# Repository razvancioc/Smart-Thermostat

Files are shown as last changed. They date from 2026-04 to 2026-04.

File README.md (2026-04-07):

# ESP32-Smart-Thermostat-Blynk-APP





**Full Doxygen Documentation:** [Click here to see it](https://razvancioc.github.io/Smart-Thermostat/)

<p align="center">
  
  <br>
  
  <br>
  
  <br>
  
  <br>
  
</p>

## Bill of Materials (BOM)

| Item / Component | Qty | Specifications / Model | Role in Project |
| :--- | :---: | :--- | :--- |
| **Microcontroller** | 1 | ESP32 Development Board | Main brain, Wi-Fi connectivity, and UI rendering. |
| **Display** | 1 | 1.69" IPS LCD Module | ST7789 driver, 240x280 resolution, SPI interface. |
| **Sensor** | 1 | DHT11 Module | Temperature and humidity reading (3-pin variant). |
| **Relay** | 1 | CW-020 5V Module | Low-level trigger; actuates the boiler's dry contact. |
| **Wiring** | Set | Jumper Wires (Dupont) | For connections between modules. |
| **Power Supply** | 1 | 5V Power Source (USB) | Powers the ESP32, which in turn provides 3.3V to the peripherals. |

## Hardware Schematic

<p align="center">
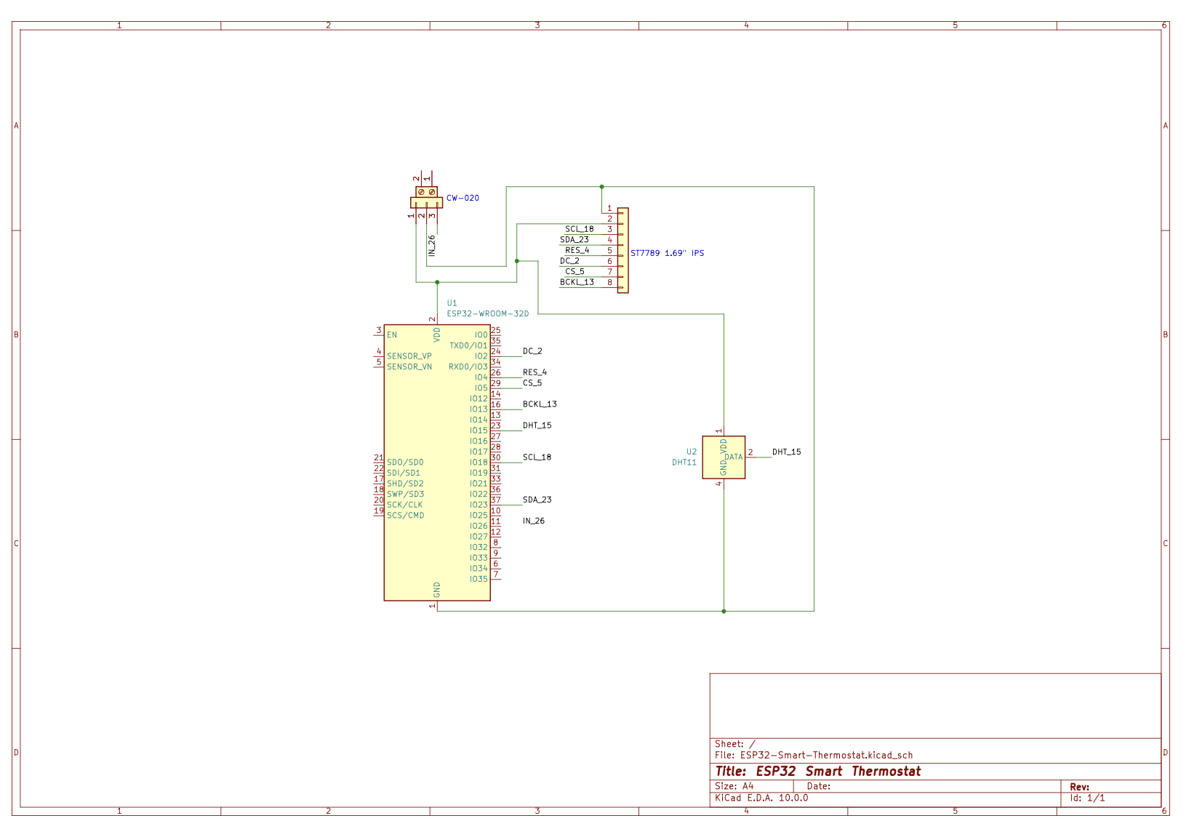
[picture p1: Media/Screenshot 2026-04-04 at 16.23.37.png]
  
</p>

## The Build Process & Engineering Journey

Building this thermostat wasn't just about putting parts together; it involved solving real hardware and software constraints. Here is how the project evolved:

### Phase 1: Breadboard Prototyping & Sensor Logic
The project started on a messy breadboard. The primary goal was to establish reliable communication between the ESP32, the DHT11 sensor, and the Blynk IoT cloud. 
* **Challenge:** The DHT11 sensor reading blocked the main loop. 
* **Solution:** Implemented `BlynkTimer` to read the sensor asynchronously every 2 seconds without halting the microcontroller.

### Phase 2: Designing the Neumorphic UI & Beating RAM Limits
I wanted a premium, "Frosted Glass" UI similar to modern smart home hubs (like Ecobee). 
* **Challenge:** Drawing complex graphics and clearing the screen (`fillScreen`) on an IPS display caused severe flickering. Attempting to use a full RAM Sprite (off-screen buffer) resulted in static/memory corruption because the ESP32 didn't have the contiguous ~134KB of free RAM required while running WiFi cryptography in the background.
* **Solution:** I engineered a **State-Tracking System**. The display now only redraws specific elements *if and only if* the temperature, humidity, or setpoint changes. Furthermore, to achieve the "transparent" text effect without RAM-heavy sprites, I dynamically matched the text background color to the underlying frosted glass circle color.

### Phase 3: Hardware Actuation & Hysteresis
Connecting the 5V CW-020 relay to safely control a boiler's dry contact.
* **Challenge:** Preventing "short-cycling" (the boiler turning on/off rapidly when the room temperature hovers exactly around the target).
* **Solution:** Programmed a `0.5°C` hysteresis logic. If the target is 22°C, heating starts at 21.5°C and stops at 22.5°C, protecting the physical hardware from premature wear.

### Phase 4: PCB Design & Professional Workflows
Transitioned from the breadboard to a formal schematic using **KiCad** to document the exact pinouts, logic-level power distribution, and safe relay wiring for future PCB fabrication. The codebase was also migrated from Arduino IDE to **Visual Studio Code (C++)**, complete with automated **Doxygen** documentation for clean, maintainable architecture.

---

## ⚠️ Critical Display Configuration (TFT_eSPI)

**Important:** If you simply compile the `main.cpp` file, the display will remain blank (white screen). The `TFT_eSPI` library requires hardware-specific configurations to know which display driver and pins you are using.

You need to inject the display settings directly into your `platformio.ini` file using build flags. Add the following to your `platformio.ini`:

```ini
build_flags =
  -D USER_SETUP_LOADED=1
  -D ST7789_DRIVER=1
  -D TFT_WIDTH=240
  -D TFT_HEIGHT=280
  -D TFT_MOSI=23
  -D TFT_SCLK=18
  -D TFT_CS=5
  -D TFT_DC=2
  -D TFT_RST=4
  -D LOAD_GLCD=1
  -D LOAD_FONT2=1
  -D LOAD_FONT4=1
  -D LOAD_FONT6=1
  -D SPI_FREQUENCY=27000000

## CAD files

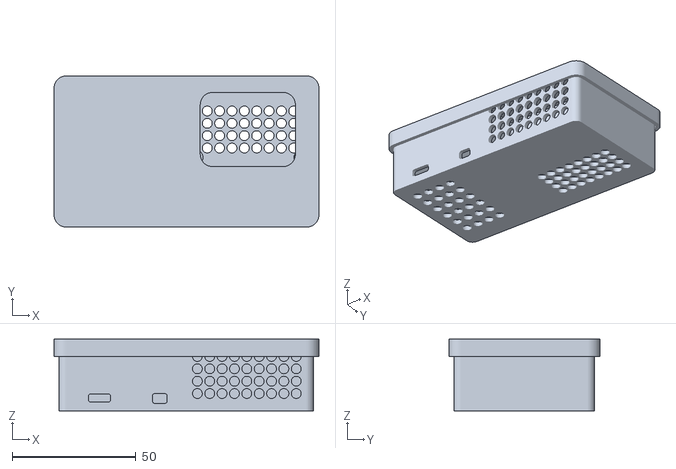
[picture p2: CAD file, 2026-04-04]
ESP32 Smart Thermostat Case.stl
107.2 x 61.2 x 29.0

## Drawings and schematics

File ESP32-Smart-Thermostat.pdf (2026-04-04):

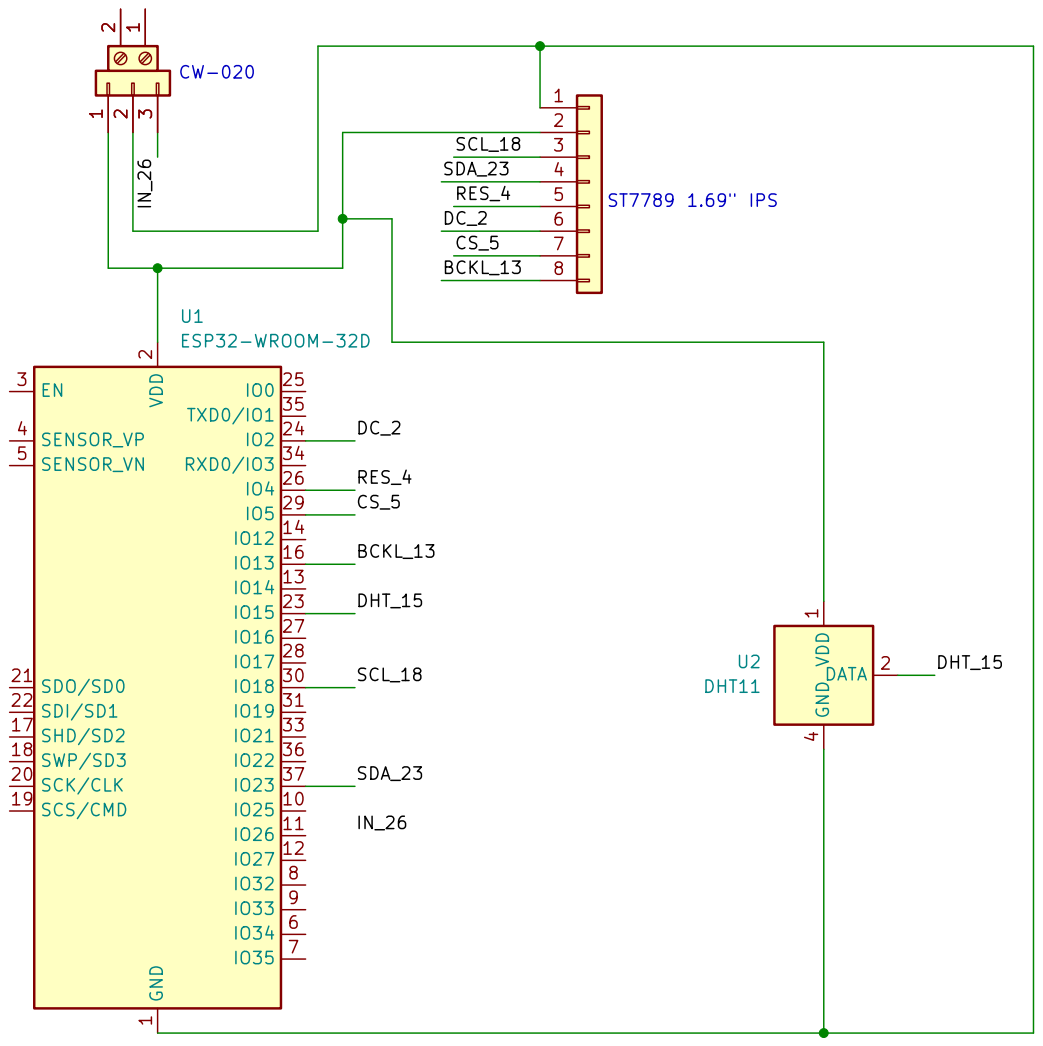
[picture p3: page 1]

Size: A4 | Rev:
KiCad E.D.A. 10.0.0 | Id: 1/1

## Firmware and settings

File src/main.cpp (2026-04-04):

/**
 * @file main.cpp
 * @brief ESP32 Smart Thermostat with TFT Display and Blynk Integration.
 * * This firmware reads environmental data from a DHT sensor, controls a heating 
 * relay based on a target setpoint with hysteresis, and displays a dynamic, 
 * anti-flickering user interface on an SPI TFT screen.
 */

// BLYNK CONFIGURATION 
#define BLYNK_TEMPLATE_ID "TMPLxxxxxxxxx"
#define BLYNK_TEMPLATE_NAME "My Thermostat"
#define BLYNK_AUTH_TOKEN "AbCdEfGhIjKlMnOpQrStUvWxYz123456"

// WIFI CONFIGURATION 
char ssid[] = "YOUR_WIFI_SSID";
char pass[] = "YOUR_WIFI_PASSWORD";

#include <WiFi.h>
#include <WiFiClient.h>
#include <BlynkSimpleEsp32.h>
#include <TFT_eSPI.h> 
#include <DHT.h>

// PINS AND HARDWARE 
#define RELAY_PIN 26
#define SENSOR_PIN 15
#define SENSOR_TYPE DHT11 
#define BACKLIGHT_PIN 13 

/** * @brief Relay Logic configuration.
 * CW-020 Relays are usually Low-Level Trigger, meaning pulling the pin to GND turns the relay ON.
 */
#define RELAY_ON LOW   
#define RELAY_OFF HIGH

DHT dht(SENSOR_PIN, SENSOR_TYPE);
TFT_eSPI tft = TFT_eSPI(); 
BlynkTimer timer;

// CURRENT VARIABLES 
float currentTemp = 0;
float humidity = 0;
float targetTemp = 22.0; 
float hysteresis = 0.5;  /**< Temperature gap to prevent rapid relay switching */
bool isHeating = false;  

// STATE TRACKING VARIABLES (For Anti-Flicker Logic)
float lastTemp = -999;
float lastHumidity = -999;
float lastTarget = -999;
bool lastHeatingState = !isHeating;
bool forceRedraw = true; /**< Forces a full screen wipe and redraw on the first boot cycle */

// COLOR PALETTE
#define COLOR_PANEL_BG TFT_BLACK 
#define COLOR_PANEL_FROST 0x2104 
#define COLOR_HEATING 0xFB00 
#define COLOR_HUMIDITY 0x3DFF 
#define COLOR_GREY_TEXT 0x8410 
#define COLOR_TEXT_WHITE TFT_WHITE

/**
 * @brief XBM Image Data for the Humidity Drop.
 * The PROGMEM keyword forces the microcontroller to store this array in Flash memory
 * instead of RAM, leaving more RAM available for dynamic variables.
 */
const unsigned char icon_drop[] PROGMEM = {
  0x00, 0x00, 0x00, 0x01, 0x80, 0x03, 0xc0, 0x07, 0xe0, 0x0f, 0xf0, 0x1f,
  0xf8, 0x3f, 0xfc, 0x7f, 0xfe, 0x7f, 0xfe, 0x7f, 0xfe, 0x3f, 0xfc, 0x1f,
  0xf8, 0x0f, 0xf0, 0x03, 0xc0, 0x00, 0x00, 0x00
};

/**
 * @brief XBM Image Data for the Heating Flame.
 */
const unsigned char icon_flame[] PROGMEM = {
  0x00, 0x00, 0x80, 0x00, 0xc0, 0x00, 0x60, 0x01, 0x30, 0x03, 0x18, 0x03,
  0xcc, 0x07, 0xce, 0x0f, 0x86, 0x1f, 0x03, 0x3f, 0x03, 0x3f, 0x82, 0x3f,
  0xc4, 0x1f, 0xf8, 0x0f, 0xf0, 0x03, 0x00, 0x00
};

/**
 * @brief Blynk App Callback: Target Temperature Slider.
 * Triggered automatically when the user changes the slider on the Blynk App (Virtual Pin 2).
 */
BLYNK_WRITE(V2) {
  targetTemp = param.asFloat();
  checkThermostat();
}

/**
 * @brief Blynk App Callback: Emergency Stop Button.
 * Forces the relay to turn off if the button on Virtual Pin 4 is pressed (value goes to 0).
 */
BLYNK_WRITE(V4) {
  if (param.asInt() == 0) {
    digitalWrite(RELAY_PIN, RELAY_OFF);
    isHeating = false;
  }
}

/**
 * @brief Standard Arduino Setup Function.
 * Initializes hardware pins, display, sensors, and network connections.
 */
void setup() {
  Serial.begin(115200);

  pinMode(BACKLIGHT_PIN, OUTPUT);
  digitalWrite(BACKLIGHT_PIN, HIGH); 
  
  pinMode(RELAY_PIN, OUTPUT);
  digitalWrite(RELAY_PIN, RELAY_OFF); 

  tft.init();
  tft.setRotation(3); 
  
  tft.fillScreen(COLOR_PANEL_BG);
  tft.setTextDatum(MC_DATUM); 
  tft.setTextColor(TFT_WHITE, COLOR_PANEL_BG); 
  tft.drawString("Connecting to WiFi...", tft.width()/2, tft.height()/2);

  dht.begin();
  Blynk.begin(BLYNK_AUTH_TOKEN, ssid, pass);

  timer.setInterval(2000L, readSensorAndControl);
}

/**
 * @brief Standard Arduino Loop Function.
 * Kept clean. Only processes Blynk cloud tasks and hardware timers.
 */
void loop() {
  Blynk.run();
  timer.run();
}

/**
 * @brief Core Application Logic.
 * Reads the DHT sensor, applies calibration offsets, updates the cloud, 
 * checks the thermostat rules, and triggers a UI redraw if any data changed.
 */
void readSensorAndControl() {
  float t = dht.readTemperature();
  float h = dht.readHumidity();

  if (isnan(t) || isnan(h)) return;

  // Temperature calibration offset (compensating for heat generated by the ESP32 chip)
  currentTemp = t - 3.0; 
  humidity = h;

  Blynk.virtualWrite(V0, currentTemp);
  Blynk.virtualWrite(V1, humidity);

  checkThermostat();

  // ANTI-FLICKER REDRAW LOGIC
  // Only redraw the display if a value has actually changed.
  // This prevents the screen from continuously blanking out and flickering every 2 seconds.
  if (currentTemp != lastTemp || humidity != lastHumidity || targetTemp != lastTarget || isHeating != lastHeatingState || forceRedraw) {
    drawInterface();
    
    lastTemp = currentTemp;
    lastHumidity = humidity;
    lastTarget = targetTemp;
    lastHeatingState = isHeating;
    forceRedraw = false;
  }
}

/**
 * @brief Evaluates the current temperature against the target setpoint.
 * Uses hysteresis to define a "deadband" so the relay doesn't rapidly click on and off 
 * when the temperature hovers exactly at the target.
 */
void checkThermostat() {
  if (currentTemp <= (targetTemp - hysteresis)) {
    digitalWrite(RELAY_PIN, RELAY_ON);
    Blynk.virtualWrite(V3, 1); 
    isHeating = true;
  } 
  else if (currentTemp >= (targetTemp + hysteresis)) {
    digitalWrite(RELAY_PIN, RELAY_OFF);
    Blynk.virtualWrite(V3, 0); 
    isHeating = false;
  }
}

/**
 * @brief Renders the Graphical User Interface on the TFT display.
 * Draws the central circle, dynamic sidebar, icons, and text.
 */
void drawInterface() {
  int w = tft.width();
  int h = tft.height();
  int centerX = (w / 2) - 15; 
  int centerY = h / 2;
  
  tft.fillScreen(COLOR_PANEL_BG);

  tft.fillCircle(centerX, centerY, 65, COLOR_PANEL_FROST);

  tft.setTextDatum(MC_DATUM); 
  
  // Set text color AND background color (COLOR_TEXT_WHITE, COLOR_PANEL_FROST).
  // Providing the background color forces the library to overwrite old pixels,
  // preventing new numbers from overlapping old ones and turning into an unreadable mess.
  tft.setTextColor(COLOR_TEXT_WHITE, COLOR_PANEL_FROST); 
  tft.setTextFont(4); 
  tft.setTextSize(2); 
  tft.drawString(String(currentTemp, 1), centerX, centerY + 5); 
  
  tft.setTextSize(1); 
  tft.setTextFont(2);
  tft.setTextColor(COLOR_GREY_TEXT, COLOR_PANEL_FROST);
  tft.drawString("inside", centerX, centerY - 35);

  int topIconY = 25;
  if(isHeating) {
    tft.setTextColor(COLOR_HEATING, COLOR_PANEL_FROST); 
    tft.drawString("HEAT", centerX, centerY + 45); 
    tft.drawXBitmap(centerX - 8, topIconY - 8, icon_flame, 16, 16, COLOR_HEATING);
  } else {
    tft.drawXBitmap(centerX - 8, topIconY - 8, icon_flame, 16, 16, COLOR_GREY_TEXT);
  }

  // Sidebar background dots
  int sidebarX = w - 15; 
  for (int yVal = 30; yVal <= h - 30; yVal += 15) {
    tft.fillCircle(sidebarX, yVal, 2, COLOR_GREY_TEXT); 
  }

  // Map the target temperature (15.0C to 30.0C) to physical Y-axis screen coordinates.
  // We multiply by 10 (150 to 300) because the map() function requires integers, not floats.
  int targetY = map(targetTemp * 10, 150, 300, h - 30, 30); 
  
  // Ternary Operator (? :): If 'isHeating' is true, use COLOR_HEATING. Otherwise, use COLOR_GREY_TEXT.
  uint16_t setpointColor = isHeating ? COLOR_HEATING : COLOR_GREY_TEXT;
  
  tft.fillCircle(sidebarX, targetY, 12, setpointColor); 
  tft.fillCircle(sidebarX, targetY, 10, COLOR_PANEL_BG); 
  
  tft.setTextDatum(MC_DATUM);
  tft.setTextColor(COLOR_TEXT_WHITE, COLOR_PANEL_BG);
  tft.setTextFont(2);
  tft.drawString(String((int)targetTemp), sidebarX, targetY);

  tft.drawXBitmap(10, h - 35, icon_drop, 16, 16, COLOR_HUMIDITY);
  
  tft.setTextDatum(BL_DATUM); 
  tft.setTextFont(4);
  tft.setTextColor(COLOR_HUMIDITY, COLOR_PANEL_BG); 
  tft.drawString(String((int)humidity) + "%", 35, h - 5); 
}
